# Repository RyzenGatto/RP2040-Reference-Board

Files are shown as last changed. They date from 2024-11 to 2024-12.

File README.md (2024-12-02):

# RP2040-Reference-Board
Compact RP2040 board ready to use with integrated projects

Download Kicad files, place into a folder, and import into KiCad. To use in your own project, copy and paste the PCB traces and the schematic into your own project and adjust nets as needed.

[This Github](https://github.com/ai03-2725/Type-C.pretty) has all of the files you need for USB C. It's also where the footprint for this project came from. 

The USB C port can be safely removed and sent through pins or a ribbon cable for a more compact design.

If you want to use this in your own project, download the kicad files and alter the file instead of trying to import the design into a preexisting file. It saves a lot of trouble.

If this is to be used in a keyboard, USB Boot can be connected to one of the keyboard keys (to ground). Otherwise, put in a push button or a way to short its pins to ground.

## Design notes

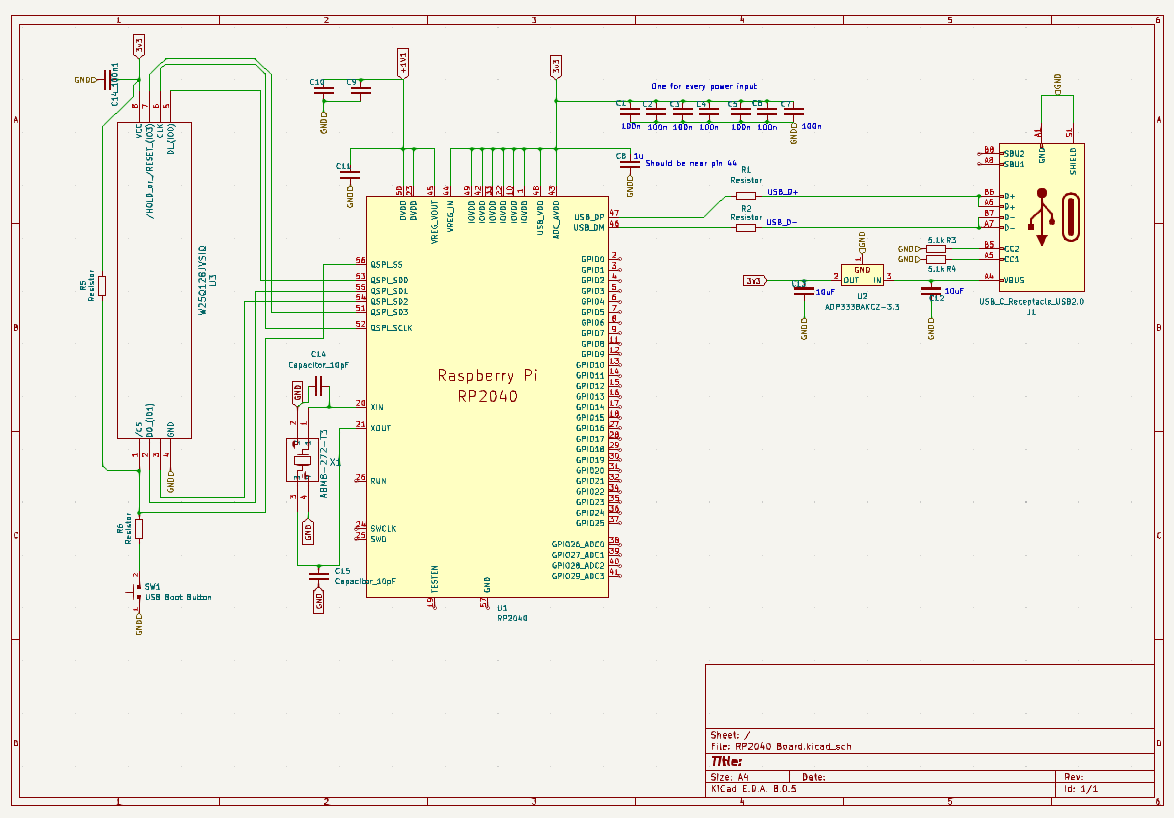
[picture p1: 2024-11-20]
Photos/Schematic.PNG

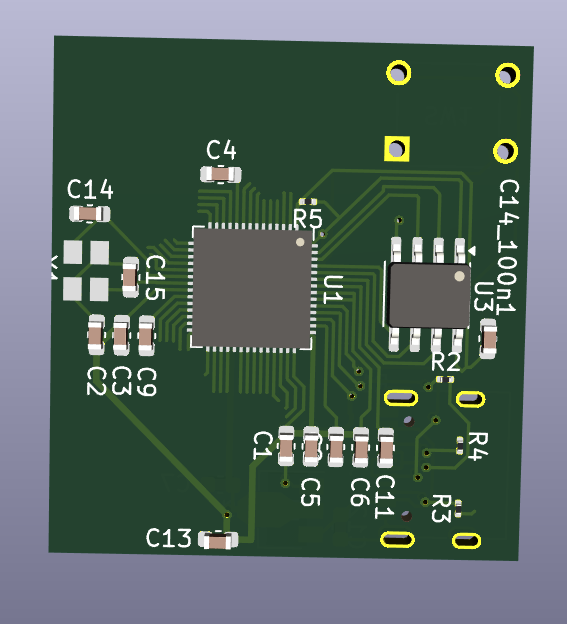
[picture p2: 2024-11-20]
Photos/image.png

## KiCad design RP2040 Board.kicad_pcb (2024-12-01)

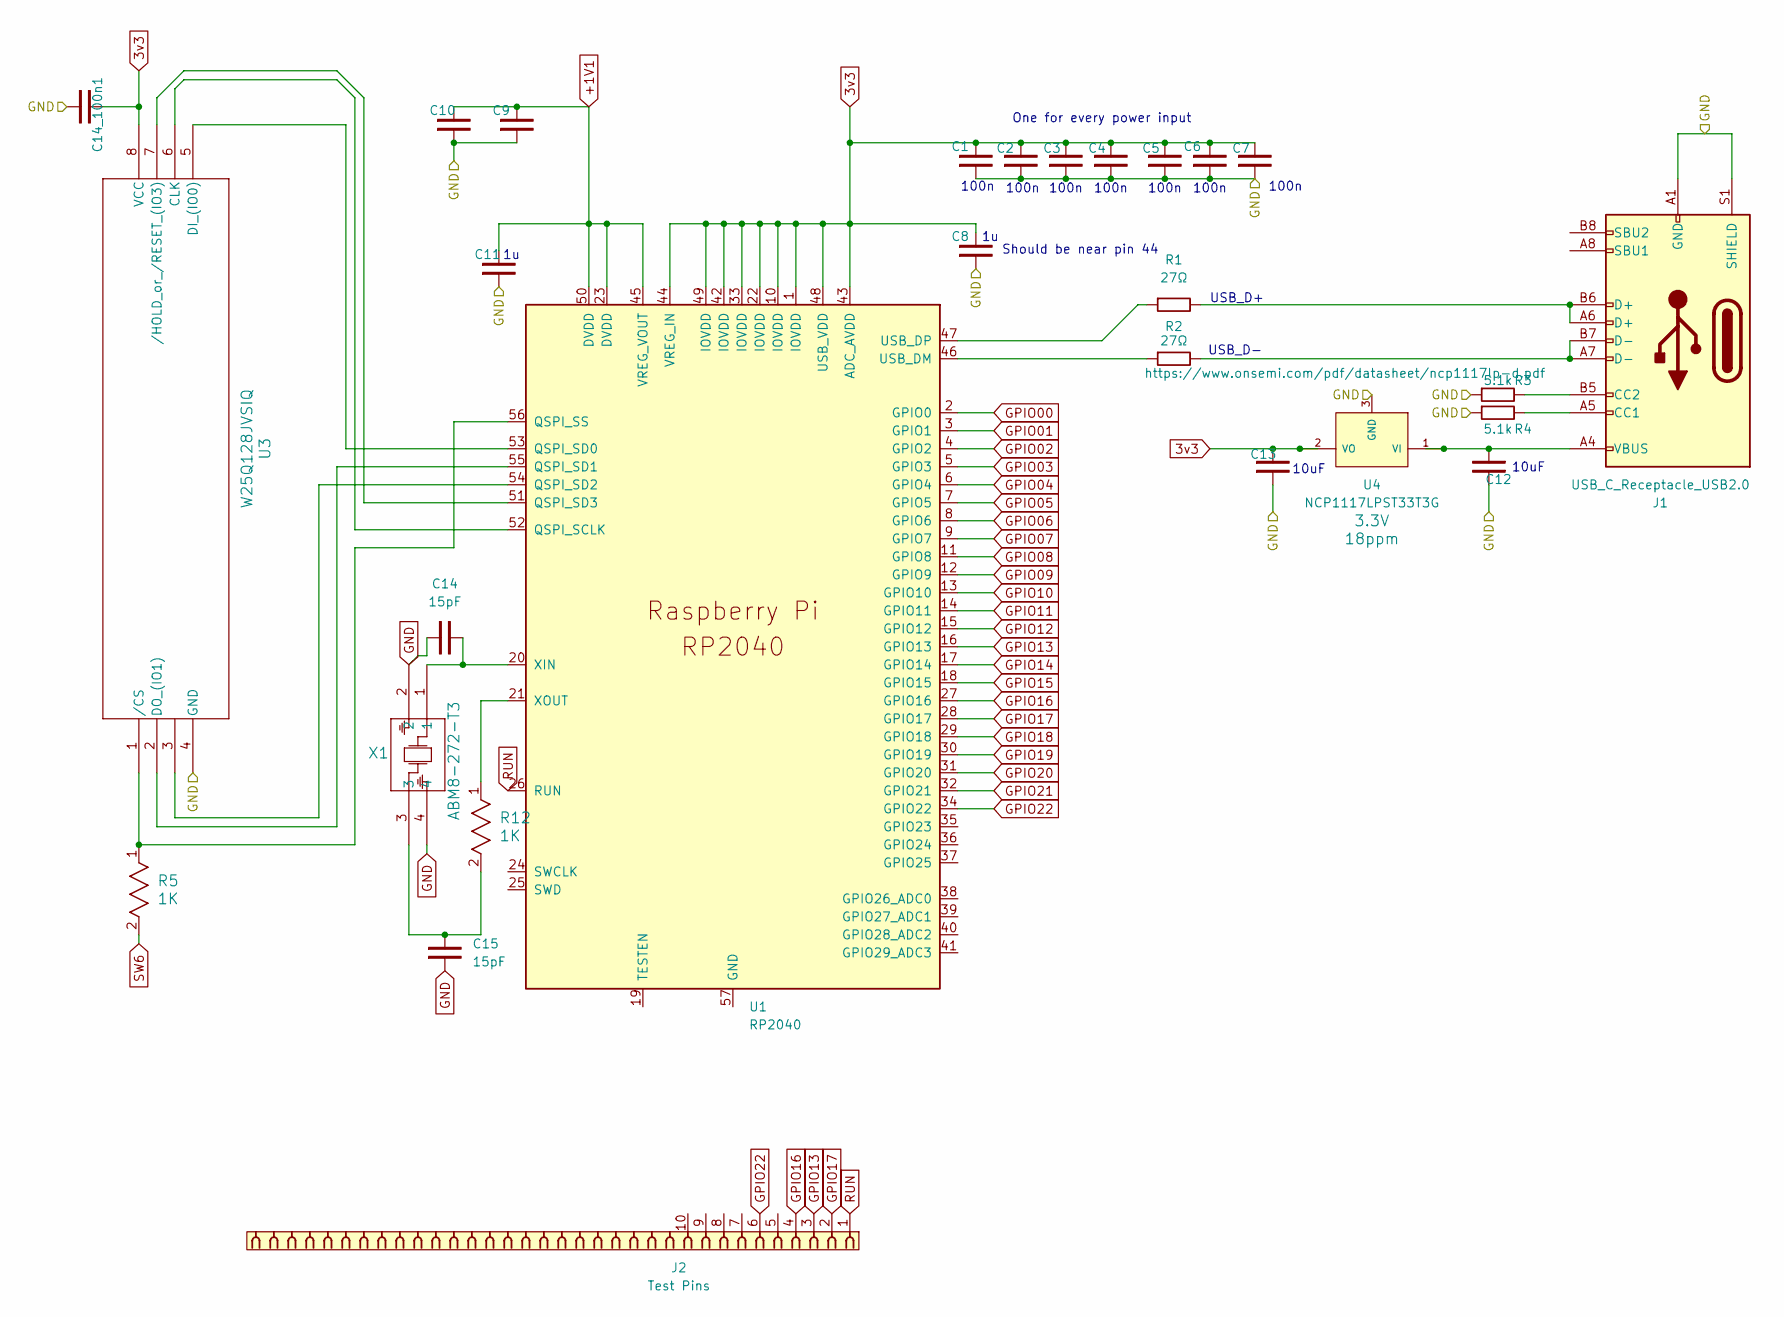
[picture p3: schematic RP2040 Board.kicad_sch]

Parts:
C1, C2, C3, C4, C5, C6, C7, C9, C10, C14_100n1: 100nF; C_0603_1608Metric; Part Number CL10E104KC8VPNC
C8, C11: 1uF; C_0603_1608Metric; Part Number CL10B105KP8NNNC
C12, C13: 10uF; C_0603_1608Metric; Part Number CL10A106MQ8NNNC
C14, C15: 15pF; C_0603_1608Metric; Part Number 885012006003
J1: USB_C_Receptacle_USB2.0; USB_C_Receptacle_G-Switch_GT-USB-7010ASV; Part Number GT-USB-7010ASV; LCSC C165948
J2: Test Pins
R1, R2: 27Ω; R_0402_1005Metric; Part Number ERJ-2RKF27R0X
R3, R4: 5.1k; R_0402_1005Metric; Part Number ERA-2AEB512X
R5, R12: 1K; RC0402N_PAN; Part Number ERJ-2RKF1001X
U1: RP2040; RP2040-QFN-56; Part Number SC0914(13)
U3: W25Q128JVSIQ; SOIC-8-1EP_3.9x4.9mm_P1.27mm_EP2.29x3mm; Part Number W25Q128JVSIQ
U4: NCP1117LPST33T3G; NCP1117; Part Number NCP1117LPST33T3G; JLCPCB ID C233715
X1: ABM8-272-T3; ABM8-272-T3_ABR; Part Number ABM8-272-T3

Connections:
3v3: C1.2, C2.2, C3.2, C4.2, C5.2, C6.2, C7.2, C8.2, C13.2, C14_100n1.2, U1.1 (IOVDD), U1.10 (IOVDD), U1.22 (IOVDD), U1.33 (IOVDD), U1.42 (IOVDD), U1.43 (ADC_AVDD), U1.44 (VREG_IN), U1.48 (USB_VDD), U1.49 (IOVDD), U3.8 (VCC), U4.2 (VO)
+1V1: C9.2, C10.2, C11.2, U1.23 (DVDD), U1.45 (VREG_VOUT), U1.50 (DVDD)
GND: C1.1, C2.1, C3.1, C4.1, C5.1, C6.1, C7.1, C8.1, C9.1, C10.1, C11.1, C12.2, C13.1, C14.1, C14_100n1.1, C15.1, J1.A1 (GND), J1.A12 (GND), J1.B1 (GND), J1.B12 (GND), J1.S1 (SHIELD), R3.1, R4.1, U1.57 (GND), U1.GND, U3.4 (GND), U4.3 (GND), X1.2, X1.4
GPIO00: U1.2 (GPIO0)
GPIO01: U1.3 (GPIO1)
GPIO02: U1.4 (GPIO2)
GPIO03: U1.5 (GPIO3)
GPIO04: U1.6 (GPIO4)
GPIO05: U1.7 (GPIO5)
GPIO06: U1.8 (GPIO6)
GPIO07: U1.9 (GPIO7)
GPIO08: U1.11 (GPIO8)
GPIO09: U1.12 (GPIO9)
GPIO10: U1.13 (GPIO10)
GPIO12: U1.15 (GPIO12)
GPIO13: J2.3, U1.16 (GPIO13)
GPIO14: U1.17 (GPIO14)
GPIO15: U1.18 (GPIO15)
GPIO16: J2.4, U1.27 (GPIO16)
GPIO17: J2.2, U1.28 (GPIO17)
GPIO18: U1.29 (GPIO18)
GPIO19: U1.30 (GPIO19)
GPIO20: U1.31 (GPIO20)
GPIO21: U1.32 (GPIO21)
GPIO22: J2.6, U1.34 (GPIO22)
unnamed: C15.2, R12.2, X1.3
unnamed: J1.A5 (CC1), R4.2
unnamed: J1.B5 (CC2), R3.2
unnamed: J1.A6 (D+), J1.B6 (D+), R1.2
unnamed: J1.A7 (D-), J1.B7 (D-), R2.2
unnamed: U1.52 (QSPI_SCLK), U3.6 (CLK)
unnamed: U1.53 (QSPI_SD0), U3.5 (DI_(IO0))
unnamed: U1.55 (QSPI_SD1), U3.2 (DO_(IO1))
unnamed: U1.54 (QSPI_SD2), U3.3
unnamed: U1.51 (QSPI_SD3), U3.7 (/HOLD_or_/RESET_(IO3))
unnamed: R5.1, U1.56 (QSPI_SS), U3.1 (/CS)
unnamed: R2.1, U1.46 (USB_DM)
unnamed: R1.1, U1.47 (USB_DP)
unnamed: C14.2, U1.20 (XIN), X1.1
unnamed: R12.1, U1.21 (XOUT)
unnamed: C12.1, J1.A4 (VBUS), J1.A9 (VBUS), J1.B4 (VBUS), J1.B9 (VBUS), U4.1 (VI)
RUN: J2.1, U1.26 (RUN)

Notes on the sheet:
100n
One for every power input
Should be near pin 44
10uF
USB_D-
USB_D+

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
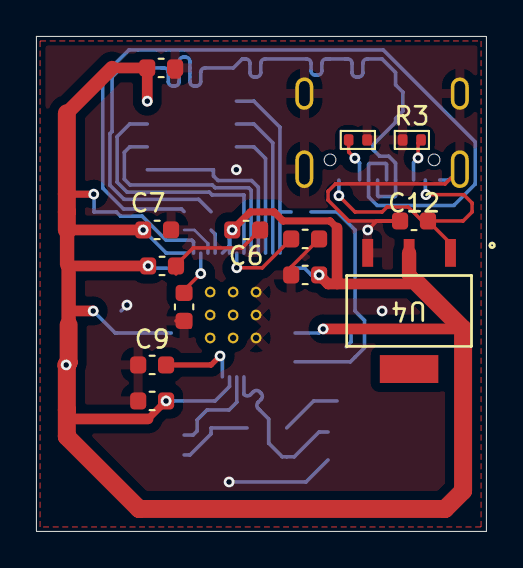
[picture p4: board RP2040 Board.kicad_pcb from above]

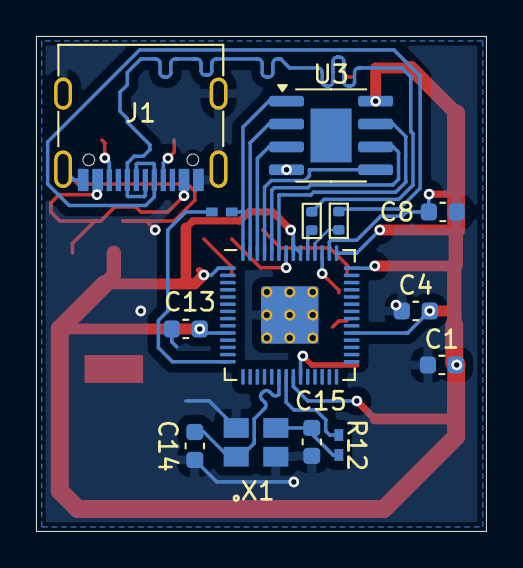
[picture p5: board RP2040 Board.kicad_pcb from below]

Board: 2 copper layers, 25.0 x 27.5 mm, 27 parts (14 on the bottom side), 20 nets.
